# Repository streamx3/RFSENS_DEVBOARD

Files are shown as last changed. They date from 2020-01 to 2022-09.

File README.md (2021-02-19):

# RFSENS DEVBOARD

STM32 based devboard for IMU sensors with RTK GPS and LoRa modems

[Quick Schematic, BOM, DRC and Assembly in PDF](RFSENS-Altium/RFSENS.pdf)

## Actual device:

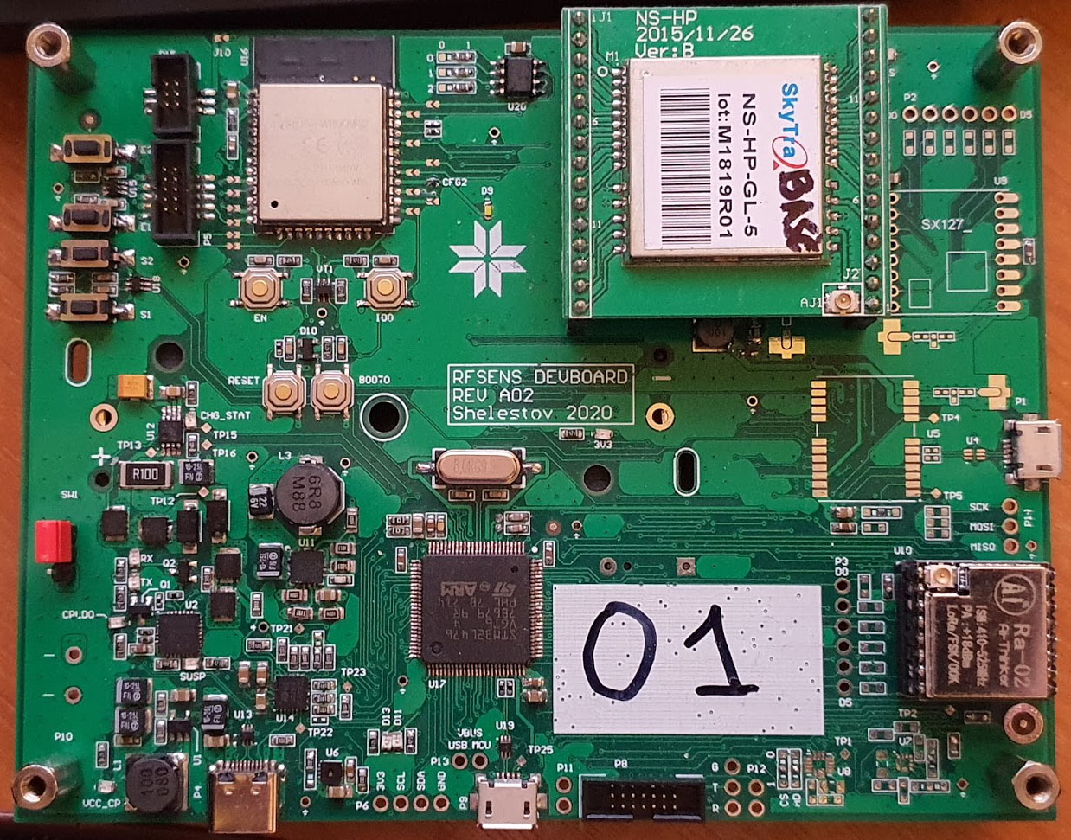
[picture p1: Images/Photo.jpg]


## Render:

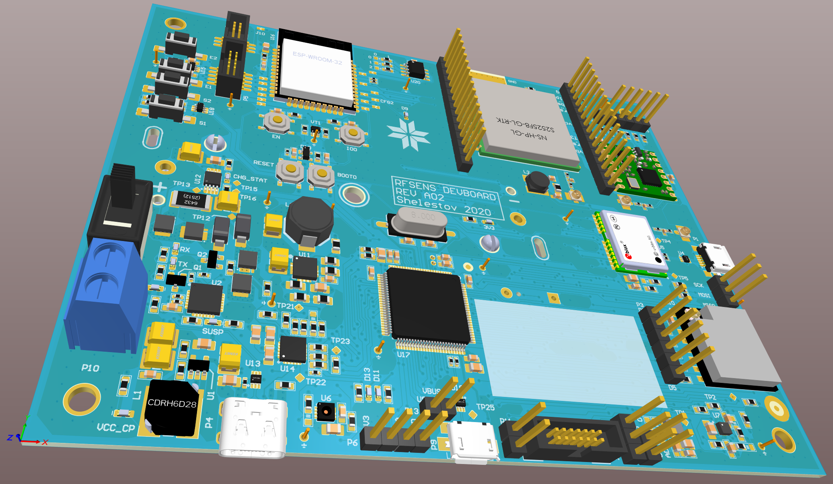
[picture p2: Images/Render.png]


## TOP:

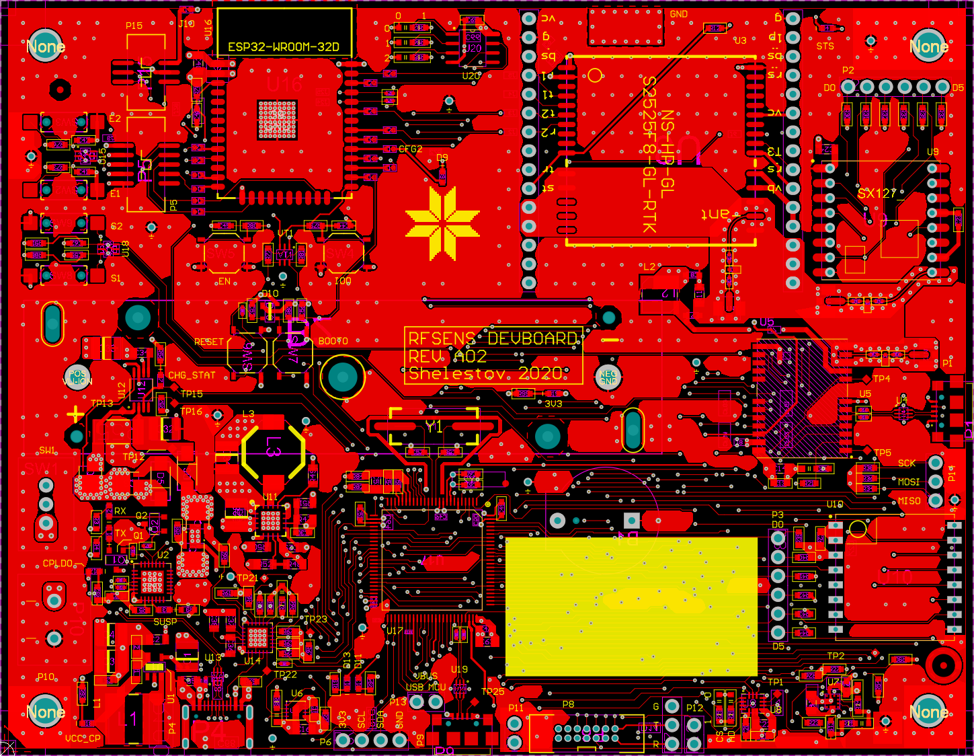
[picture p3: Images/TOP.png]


## BOT:

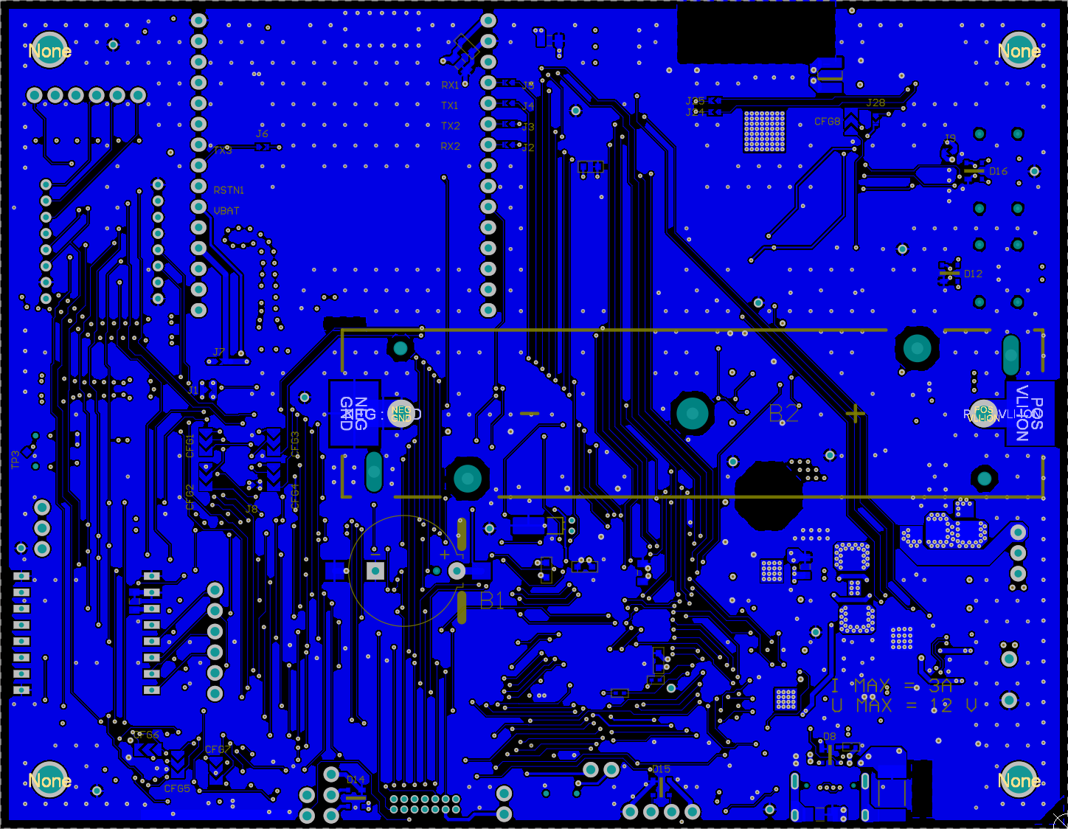
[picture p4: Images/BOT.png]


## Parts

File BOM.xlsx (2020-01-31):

DesignItemId | Description | Designator | Blueprint Quantity | Owned | Kosmodrom | PriceKosmodromUAH | RCS | PriceRCSUAH | OtherUA | PriceUAH | DigiKey | PriceDigiKey | Mouser | PriceMouser | Aliexpress | PriceAliexpress | HDR |  | PRICE USING | FULL Quantity | FULL Price | Light Quantity | Light Price
74HC2G14 | Dual inverting Schmitt trigger | U15, U18 | 2 |  | http://www.kosmodrom.com.ua/el.php?name=74HC2G14GW.125 | 4,5 |  |  |  |  |  |  |  |  |  |  |  |  | 4,5 | 2 | 9 | 2 | 9
18650_KEYS1042_HOLDER | 18650 Li-ion Battery Holder | B2 | 1 |  | http://www.kosmodrom.com.ua/el.php?name=KEYS1042 | 19,5 |  |  |  |  |  |  |  |  |  |  |  |  | 19,5 | 1 | 19.5 | 1 | 19.5
ANT-U.FL | Generic U.FL connector with 1 ANT + 3 GND | ANT1, ANT2, ANT3 | 3 | 6 | http://www.kosmodrom.com.ua/el.php?name=U.FL-R-SMT-1[10] | 4,75 | https://radiomag.prom.ua/p754064376-ipex-vilka-platu.html | 6 |  |  |  |  |  |  |  |  |  |  | 4,75 | 3 | 14.25 | 3 | 14.25
BC847BDW1T1G | Dual General Purpose Transistors NPN SOT 363 | VT1 | 1 |  | http://www.kosmodrom.com.ua/el.php?name=BC847BDW1T1G | 1,5 |  |  |  |  |  |  |  |  |  |  |  |  | 1,5 | 1 | 1.5 | 1 | 1.5
BH-6_UART_ESP-PROG | 1,27 mm 2x3 Header | P15 | 1 | 20 |  |  |  |  |  |  |  |  |  |  | https://www.aliexpress.com/item/4000400690967.html?spm=a2g0s.9042311.0.0.cbd34c4duRVTSV | 7 |  |  | 170.10 | 1 | 170.1 | 1 | 170.1
BH-10_JTAG_ESP-PROG | 1,27 mm 2x5 Header | P5 | 1 | 10 | http://www.kosmodrom.com.ua/el.php?name=BH1.27SMD-10 | 7 |  |  |  |  |  |  |  |  |  |  |  |  | 7 | 1 | 7 | 1 | 7
BH-14_JTAG_STLINK | 1,27 mm 2x7 Header | P8 | 1 | 10 | http://www.kosmodrom.com.ua/el.php?name=BH1.27-14 | 7,75 |  |  |  |  |  |  |  |  |  |  |  |  | 7,75 | 1 | 7.75 | 1 | 7.75
BSS84LT1G | Power MOSFET Single P-Channel SOT-23 -50 V, 10 _x0002_ | Q1, Q2 | 2 |  | http://www.kosmodrom.com.ua/el.php?name=BSS84LT1G | 1,75 |  |  |  |  |  |  |  |  |  |  |  |  | 1,75 | 2 | 3.5 | 2 | 3.5
C0402_10pF_50V | Ceramic capacitor | C11, C12, C25 | 3 |  |  |  | https://www.rcscomponents.kiev.ua/product/10pf-50v-1-cog-0402-vj0402a100fxacw1bc-vishay_162340.html | 0,3 |  |  |  |  |  |  |  |  |  |  | 0,3 | 3 | 0.9 | 3 | 0.9
C0603_1nF_25V | Ceramic capacitor | C41, C42, C43, C44, C45, C52, C56, C59, C62 | 9 |  | http://www.kosmodrom.com.ua/el.php?name=CP0603100050V10 | 0,75 |  |  |  |  |  |  |  |  |  |  |  |  | 0,75 | 9 | 6.75 | 9 | 6.75
C0603_4.3pF_50V | Ceramic capacitor | C60, C61 | 2 |  | http://www.kosmodrom.com.ua/el.php?name=CP06034.350V0.25 | 0,25 |  |  |  |  |  |  |  |  |  |  |  |  | 0,25 | 2 | 0.5 | 2 | 0.5
C0603_10nF_16V | Ceramic capacitor | C55 | 1 |  | http://www.kosmodrom.com.ua/el.php?name=CP06031050V10 | 0,25 |  |  |  |  |  |  |  |  |  |  |  |  | 0,25 | 1 | 0.25 | 1 | 0.25
C0603_10pF_25V | Ceramic capacitor | C30 | 1 |  |  |  | https://www.rcscomponents.kiev.ua/product/10pf-50v-np0-0-25pf-0603-4k-reel-c0603n100c500nt-hitano-kondensator-keramicheskij-smd_3301.html | 0,45 |  |  |  |  |  |  |  |  |  |  | 0,45 | 1 | 0.45 | 1 | 0.45
C0603_20pF_50V | Ceramic capacitor | C57, C58 | 2 |  | http://www.kosmodrom.com.ua/el.php?name=CP06032050V5 | 0,25 |  |  |  |  |  |  |  |  |  |  |  |  | 0,25 | 2 | 0.5 | 2 | 0.5
C0603_100nF_16V | Ceramic capacitor | C5, C6, C7, C8, C9, C13, C15, C17, C19, C20, C21, C23, C26, C46, C47, C48, C49, C50, C51, C54, C65 | 21 |  | http://www.kosmodrom.com.ua/el.php?name=CP06030.125V8020 | 1 |  |  |  |  |  |  |  |  |  |  |  |  | 1 | 21 | 21 | 21 | 21
C0805_1uF_25V | Ceramic capacitor | C2, C10, C14, C16, C18, C22, C24, C27, C29, C35, C36, C37, C38, C40, C53, C63, C64, C66 | 18 |  | http://www.kosmodrom.com.ua/el.php?name=CP0805125V10 | 1 |  |  |  |  |  |  |  |  |  |  |  |  | 1 | 18 | 18 | 18 | 18
C0805_100nF_25V | Ceramic capacitor | C34, C67 | 2 |  |  |  | https://www.rcscomponents.kiev.ua/product/100nf-25v-x7r-10-0805-4k-reel-c0805b104k250nt-hitano-kondensator-keramicheskij-smd_2259.html | 1,1 |  |  |  |  |  |  |  |  |  |  | 1,1 | 2 | 2.2 | 2 | 2.2
C1206_1nF_2KV | Ceramic capacitor | C68 | 1 |  |  |  | https://www.rcscomponents.kiev.ua/product/1nf-2000v-x7r-10-1206-3k-reel-1206b102k202n3-hitano-kondensatory-keramicheskie-smd_11455.html | 1,7 |  |  |  |  |  |  |  |  |  |  | 1,7 | 1 | 1.7 | 1 | 1.7
CAP_B_10uF_6V3 | Tantalum capacitor | C33 | 1 |  |  |  | https://www.rcscomponents.kiev.ua/product/10uf-10v-size-b-10-tajb106k010r-avx-kondensator-tantalovyj-smd_14318.html | 4 |  |  |  |  |  |  |  |  |  |  | 4 | 1 | 4 | 1 | 4
CAP_B_10uF_25V | Tantalum capacitor | C1, C3, C4, C28, C32 | 5 |  | http://www.kosmodrom.com.ua/el.php?name=TR3B106K025C0450 | 6,75 | https://www.rcscomponents.kiev.ua/product/10uf-25v-size-b-10-tajb106k025rnj-avx-kondensator-tantalovyj-smd_39635.html | 5,5 |  |  |  |  |  |  |  |  |  |  | 5,5 | 5 | 27.5 | 5 | 27.5
CAP_B_22uF_6V3 | Tantalum capacitor | C31 | 1 |  |  |  | https://www.rcscomponents.kiev.ua/product/22uf-6-3v-size-b-20-tcscs0j226mbar-samsung-kondensator-tantalovyj-smd_6588.html | 4,5 |  |  |  |  |  |  |  |  |  |  | 4,5 | 1 | 4.5 | 1 | 4.5
CAP_B_100uF_6V3 | Tantalum capacitor | C39 | 1 |  |  |  | https://www.rcscomponents.kiev.ua/product/100uf-6-3v-size-b-10-tajb107k006rnj-avx-kondensator-tantalovyj-smd_39633.html | 5,5 |  |  |  |  |  |  |  |  |  |  | 5,5 | 1 | 5.5 | 1 | 5.5
CON-USB-Micro/Mini | Mini/Micro USB B Type RCPT | P1, P9 | 2 |  | http://www.kosmodrom.com.ua/el.php?name=ESB228110100Z | 2,5 |  |  |  |  |  |  |  |  |  |  |  |  | 2,5 | 2 | 5 | 2 | 5
CON-USB-TYPE-C-B-229 | Type C 3A Throughthole Shell, USB2 + PD SMD pins | P4 | 1 |  | http://www.kosmodrom.com.ua/el.php?name=USB-Type-C-B-229 | 8,25 |  |  |  |  |  |  |  |  |  |  |  |  | 8,25 | 1 | 8.25 | 1 | 8.25
CP2102-GM | SINGLE-CHIP USB-TO-UART BRIDGE | U2 | 1 |  | http://www.kosmodrom.com.ua/el.php?name=CP2102-GMR | 46,75 |  |  |  |  |  |  |  |  |  |  |  |  | 46,75 | 1 | 46.75 | 1 | 46.75
CR12XX_BH500 | Coin Cell Battery 3V 12 X 2.5 mm 48mA Holder | B1 | 1 |  | http://www.kosmodrom.com.ua/el.php?name=BH500 | 8,25 |  |  |  |  |  |  |  |  |  |  |  |  | 8,25 | 1 | 8.25 | 1 | 8.25
D_SS-34 | Rectifier, Schottky; DO-214AB; 3.0A IF; 0.75V; 40V; 100A IFRM; 10000V/us; 1000pF | D5, D6 | 2 |  |  |  | https://www.rcscomponents.kiev.ua/product/ss34a_123319.html | 4 |  |  |  |  |  |  |  |  |  |  | 4 | 2 | 8 | 2 | 8
DC_TERM_BLK |  | P10 | 1 |  |  |  | https://www.rcscomponents.kiev.ua/product/klemmnik-dg301-5-0-02p-12-00a-h-2kont-sinij-shlicz-degson_19759.html | 1,75 |  |  |  |  |  |  |  |  |  |  | 1,75 | 1 | 1.75 | 1 | 1.75
ESP32-WROOM-32D | IC: SoC; GPIO, I2C, I2S, IR, SD, SDIO, SPI, UART; 2.7Г·3.6VDC; 20dBm | U16 | 1 | 2 |  |  |  |  | https://www.olx.ua/uk/obyavlenie/esp-wroom-32-esp-32-module-IDGzoQv.html | 135 |  |  |  |  | https://www.aliexpress.com/item/32963147246.html | 2,5 |  |  | 60.75 | 1 | 60.75 | 1 | 60.75
HEADER 1x2 |  | P11, P12, P13 | 3 |  |  |  |  |  |  |  |  |  |  |  |  |  | 2 | 6 | 0.00 | 3 | 0 | 3 | 0
HEADER 1x3 |  | P14 | 1 |  |  |  |  |  |  |  |  |  |  |  |  |  | 3 | 3 | 0.00 | 1 | 0 | 1 | 0
HEADER 1x4 |  | P6 | 1 |  |  |  |  |  |  |  |  |  |  |  |  |  | 4 | 4 | 0.00 | 1 | 0 | 1 | 0
HEADER 1x6 |  | P2, P3 | 2 |  |  |  |  |  |  |  |  |  |  |  |  |  | 5 | 10 | 0.00 | 2 | 0 | 2 | 0
IRFHM9331 | -30V Single P-Channel HEXFET Power MOSFET in a PQFN 3mm x 3mm package | Q3, Q4, Q5, Q6 | 4 |  | http://www.kosmodrom.com.ua/el.php?name=IRFHM9331TRPBF | 11,75 |  |  |  |  |  |  |  |  |  |  |  |  | 11,75 | 4 | 47 | 4 | 47
L_CDHR8D43_6.8uH_3.9A | Inductor Generic | L3 | 1 |  | http://www.kosmodrom.com.ua/el.php?name=CDRH8D43NP-6R8NC | 12 |  |  |  |  |  |  |  |  |  |  |  |  | 12 | 1 | 12 | 1 | 12
L_CDRH4D18_10uH_0.61A | Inductor Generic | L2 | 1 |  | http://www.kosmodrom.com.ua/el.php?name=CDRH4D18NP-100NC | 7 |  |  |  |  |  |  |  |  |  |  |  |  | 7 | 1 | 7 | 1 | 7
L_CDRH6D28_10uH_1.7A | Inductor Generic | L1 | 1 |  | http://www.kosmodrom.com.ua/el.php?name=CDRH6D28NP-100NC | 6,25 |  |  |  |  |  |  |  |  |  |  |  |  | 6,25 | 1 | 6.25 | 1 | 6.25
LED | Led General | D1, D2, D3, D4, D7, D9, D11, D13, D17, D18, D19 | 11 | 3000 |  |  |  |  |  |  |  |  |  |  |  |  |  |  | 0.00 | 11 | 0 | 11 | 0
LIS3MDLTR | LIS3MDL Series 3 Axis В±2/В±8/В±12/В±16 g 3.6V High Performance Magnetometer LGA-12 | U7 | 1 |  | http://www.kosmodrom.com.ua/el.php?name=LIS3MDLTR | 57,5 |  |  |  |  |  |  |  |  |  |  |  |  | 57,5 | 1 | 57.5 | 1 | 57.5
LSM6DSOX | Gygo and acceletometer programmable I2C master IC | U8 | 1 | 10 |  |  |  |  |  |  | https://www.digikey.com/product-detail/en/stmicroelectronics/LSM6DSOXTR/497-18367-1-ND/9841887 | 5,25 | https://www.mouser.com/ProductDetail/STMicroelectronics/LSM6DSOXTR | 4,76 |  |  |  |  | 115.67 | 1 | 115.668 | 1 | 115.668
M24C64-WDW6T | 64Kbit Serial I2C Bus EEPROM | U20 | 1 |  | http://www.kosmodrom.com.ua/el.php?name=M24C64-WMN6TP | 5 |  |  |  | - |  |  |  |  |  |  |  |  | 5 | 1 | 5 | 1 | 5
MCP73843 | MCP73843 Single Li-ion cell charger IC | U12 | 1 |  | http://www.kosmodrom.com.ua/el.php?name=MCP73843-420IMS | 64,25 |  |  |  |  |  |  |  |  |  |  |  |  | 64,25 | 1 | 64.25 | 1 | 64.25
NEO | u-blox NEO GNSS module | U5 | 1 |  |  |  |  |  | https://www.u-blox.com/en/product/neo-m8-series | 22.10 |  |  |  |  |  |  |  |  | 597.36 | 1 | 597.363 | 1 | 597.363
NS-HP-GL | NS-HP-GL / S2525F8-GL-RTK in SMD | U3 | 1 | 2 |  |  |  |  | http://navspark.mybigcommerce.com/ns-hp-gl-gps-glonass-rtk-receiver/ | 70 |  |  |  |  |  |  |  |  | 1892.10 | 1 | 1892.1 |  | 0
PRTR5V0U2X,215 | PRTR5V0U2X - Ultra low capacitance double rail-to-rail ESD protection diode | D8, D10, D12, D14, D15, D16 | 6 | 10 | http://www.kosmodrom.com.ua/el.php?name=PRTR5V0U2X.215 | 3,25 |  |  |  |  |  |  |  |  |  |  |  |  | 3,25 | 6 | 19.5 | 6 | 19.5
Q_8MHz | Quartz resonator 8MHz | Y1 | 1 |  | http://www.kosmodrom.com.ua/el.php?name=KX-K-8.0-MHz | 6 |  |  |  |  |  |  |  |  |  |  |  |  | 6 | 1 | 6 | 1 | 6
Q_32.768KHz | Quartz resonator 32.768KHz | Y2 | 1 |  | http://www.kosmodrom.com.ua/el.php?name=KX-38T-32.768-kHz-6pF | 5 |  |  |  |  |  |  |  |  |  |  |  |  | 5 | 1 | 5 | 1 | 5
R0402_0R | Resistor General | R13, R14, R15, R16, R17, R18, R45, R46, R53, R58, R74, R75, R98 | 13 |  | http://www.kosmodrom.com.ua/el.php?name=0402SMDRES0OM5 | 0,04 | https://www.rcscomponents.kiev.ua/product/0-ohm-0402-wr04x000ptl-walsin_105536.html | 0,05 |  |  |  |  |  |  |  |  |  |  | 0,04 | 13 | 0.52 | 13 | 0.52
R0402_51R | Resistor General | R6, R7, R8, R10, R83, R86, R87, R101, R102 | 9 |  | http://www.kosmodrom.com.ua/el.php?name=0402SMDRES51OM5 | 0,03 | https://www.rcscomponents.kiev.ua/product/51-ohm-5-1-16w-50v-0402-rc0402jr-51r-hitano_11504.html | 0,05 |  |  |  |  |  |  |  |  |  |  | 0,03 | 9 | 0.27 | 9 | 0.27
R0603_0R | Resistor General | R21, R23, R82, R84 | 4 |  |  |  | https://www.rcscomponents.kiev.ua/product/0-ohm-5-0-1w-50v-0603-rc0603jr-0r-hitano-rezistor-smd_4159.html | 0,06 |  |  |  |  |  |  |  |  |  |  | 0,06 | 4 | 0.24 | 4 | 0.24
R0603_1K | Resistor General | R69, R70 | 2 |  |  |  | https://www.rcscomponents.kiev.ua/product/1-kohm-5-0-1w-50v-0603-0603waj0102t5e-uniohm_147392.html | 0,06 |  |  |  |  |  |  |  |  |  |  | 0,06 | 2 | 0.12 | 2 | 0.12
R0603_1K_1% | Resistor General | R60 | 1 |  |  |  | https://www.rcscomponents.kiev.ua/product/1-kohm-1-0-1w-50v-0603-rc0603fr-1kr-hitano-rezistor-smd_95976.html | 0,07 |  |  |  |  |  |  |  |  |  |  | 0,07 | 1 | 0.07 | 1 | 0.07
R0603_4K7 | Resistor General | R5, R26, R27, R54, R90 | 5 | 3000 |  |  |  |  |  |  |  |  |  |  |  |  |  |  | 0.00 | 5 | 0 | 5 | 0
R0603_10K | Resistor General | R22, R30, R31, R32, R33, R34, R35, R36, R37, R38, R39, R40, R41, R42, R43, R44, R61, R62, R63, R64, R65, R66, R67, R68, R73, R76, R88, R91 | 28 | 3000 |  |  | https://www.rcscomponents.kiev.ua/product/10-kohm-5-0-1w-50v-0603-rc0603jr-0710kl-yageo_107096.html | 0,06 |  |  |  |  |  |  |  |  |  |  | 0.00 | 28 | 0 | 28 | 0
R0603_10K_1% | Resistor General | R59 | 1 |  |  |  | https://www.rcscomponents.kiev.ua/product/10-kohm-1-0-1w-50v-0603-rc0603fr-10kr-hitano-rezistor-smd_8516.html | 0,07 |  |  |  |  |  |  |  |  |  |  | 0.00 | 1 | 0 | 1 | 0
R0603_12K | Resistor General | R77, R78, R81 | 3 | 3000 |  |  | https://www.rcscomponents.kiev.ua/product/12-kohm-5-0-1w-50v-0603-rc0603jr-12k0-hitano-rezistor-smd_1014.html | 0,06 |  |  |  |  |  |  |  |  |  |  | 0.00 | 3 | 0 | 3 | 0
R0603_20K_1% | Resistor General | R2 | 1 |  |  |  | https://www.rcscomponents.kiev.ua/product/20-kohm-1-0-1w-50v-0603-rc0603fr-20kr-hitano-rezistor-smd_16748.html | 0,07 |  |  |  |  |  |  |  |  |  |  | 0.00 | 1 | 0 | 1 | 0
R0603_100K | Resistor General | R57 | 1 | 3000 |  |  |  |  |  |  |  |  |  |  |  |  |  |  | 0.00 | 1 | 0 | 1 | 0
R0603_105K_1% | Resistor General | R1 | 1 |  |  |  | https://www.rcscomponents.kiev.ua/product/105-kohm-1-0-1w-50v-0603-rc0603fr-105k0-hitano-rezistor-smd_39565.html | 0,07 |  |  |  |  |  |  |  |  |  |  | 0.00 | 1 | 0 | 1 | 0
R0603_470R | Resistor General | R3, R4, R9, R12, R19, R56, R72, R79, R80, R85, R92, R93, R94, R99 | 14 | 3000 |  |  |  |  |  |  |  |  |  |  |  |  |  |  | 0.00 | 14 | 0 | 14 | 0
R0805_0R | Resistor General | R11 | 1 | 3000 |  |  |  |  |  |  |  |  |  |  |  |  |  |  | 0.00 | 1 | 0 | 1 | 0
R0805_1M_1% | Resistor General | R48, R49, R50 | 3 |  | http://www.kosmodrom.com.ua/el.php?name=SMDRES08051MOM1 | 0,17 | https://www.rcscomponents.kiev.ua/product/1-mohm-1-0-125w-150v-0805-rc0805fr-1mr-hitano_11448.html | 0,11 |  |  |  |  |  |  |  |  |  |  | 0,11 | 3 | 0.33 | 3 | 0.33
R0805_261K_1% | Resistor General | R52 | 1 |  |  |  | https://www.rcscomponents.kiev.ua/product/261-kohm-1-0-125w-150v-0805-rc0805fr-261k-hitano-rezistor-smd_27749.html | 0,11 |  |  |  |  |  |  |  |  |  |  | 0,11 | 1 | 0.11 | 1 | 0.11
R0805_300K_1% | Resistor General | R51 | 1 |  | http://www.kosmodrom.com.ua/el.php?name=SMDRES0805300KOM1 | 0,12 | https://www.rcscomponents.kiev.ua/product/300-kohm-1-0-125w-150v-0805-rezistor-smd_3009.html | N/A |  |  |  |  |  |  |  |  |  |  | 0,12 | 1 | 0.12 | 1 | 0.12
R0805_560K_1% | Resistor General | R47 | 1 |  | http://www.kosmodrom.com.ua/el.php?name=SMDRES0805560KOM1 | 0,17 | https://www.rcscomponents.kiev.ua/product/560-kohm-1-0-125w-150v-0805-rc0805fr-560kr-hitano_1487.html | 0,11 |  |  |  |  |  |  |  |  |  |  | 0,11 | 1 | 0.11 | 1 | 0.11
R2512_0R1_1% | Resistor General | R55 | 1 |  | http://www.kosmodrom.com.ua/el.php?name=SMDRES25120.1OM5 | 2,25 |  |  |  |  |  |  |  |  |  |  |  |  | 2,25 | 1 | 2.25 | 1 | 2.25
R2512_1M_5% | Resistor General | R100 | 1 |  |  |  | https://www.rcscomponents.kiev.ua/product/1-mohm-5-1w-2512-rc2512jk-1mr-hitano-rezistor-smd_51251.html | 0,75 |  |  |  |  |  |  |  |  |  |  | 0,75 | 1 | 0.75 | 1 | 0.75
RA-02 | RA-02 LoRa modem by Ai-Thinker | U10 | 1 | 6 |  |  |  |  | https://1wire.com.ua/ra-02-lora-sx1278-433mhz.html | 127,66 |  |  |  |  | https://www.aliexpress.com/item/32976593804.html | 2,65 |  |  | 64.39 | 1 | 64.395 | 1 | 64.395
RJ0603_10K | Resistor General | R20, R24, R25, R28, R29, R71, R89, R95, R96, R97 | 10 | 3000 |  |  | https://www.rcscomponents.kiev.ua/product/10-kohm-5-0-1w-50v-0603-rc0603jr-0710kl-yageo_107096.html | 0,06 |  |  |  |  |  |  |  |  |  |  | 0,06 | 10 | 0.6 | 10 | 0.6
SHT30-DIS | Temp & Humidity sensor | U6 | 1 |  | http://www.kosmodrom.com.ua/el.php?name=SHT30-DIS-B | 75,75 |  |  |  |  |  |  |  |  |  |  |  |  | 75,75 | 1 | 75.75 | 0 | 0
STM32L476VGT | Ultra-low-power Cortex-M4 32-bit MCU+FPU, 100DMIPS, up to 1MB Flash, 128 KB SRAM, USB OTG FS, LCD | U17 | 1 | 6 |  |  |  |  | https://step-elektronika.prom.ua/p499466797-mikrokontroller-shirokogo-naznacheniya.html | 253,84 | https://www.digikey.com/product-detail/en/stmicroelectronics/STM32L476VGT6/497-15873-ND/5344349 | 10.55 | https://www.mouser.com/ProductDetail/STMicroelectronics/STM32L476VGT6TR | 10.55 |  |  |  |  | 253,84 | 1 | 253.84 | 1 | 253.84
STUSB1602 | USB Type-C controller with TX/RX line driver and BMC | U14 | 1 |  |  |  | https://www.rcscomponents.kiev.ua/product/stusb1602aqtr_132330.html | 45 |  |  |  |  |  |  |  |  |  |  | 45 | 1 | 45 | 1 | 45
SWI_2.54_2POS | Generich 2 pos switch | SW1 | 1 |  |  |  |  |  |  |  |  |  |  |  |  |  | 3 | 3 | 0.00 | 1 | 0 | 1 | 0
SWITCH_GEN_2P | SWITCH DIP 4.3 mm | SW2, SW3, SW8, SW9 | 4 |  | http://www.kosmodrom.com.ua/el.php?name=TACT-35N-F | 1,25 |  |  |  |  |  |  |  |  |  |  |  |  | 1,25 | 4 | 5 | 4 | 5
SWITCH_GEN_4P | SWITCH DIP 4.3 mm | SW4, SW5, SW6, SW7 | 4 |  | http://www.kosmodrom.com.ua/el.php?name=TACT-5X5X1.5 | 0,5 |  |  |  |  |  |  |  |  |  |  |  |  | 0,5 | 4 | 2 | 4 | 2
SX1278 | SX1278 LoRa modem | U9 | 1 | 2 |  |  |  |  |  |  |  |  |  |  | https://www.aliexpress.com/item/32802402060.html | 3,76 |  |  | 91.37 | 1 | 91.368 |  | 0
TPS62110RSAT | TPS6211x 17-V, 1.5-A, Synchronous Step-Down Converter | U11 | 1 |  | http://www.kosmodrom.com.ua/el.php?name=TPS62110RSAT | 64 |  |  |  |  |  |  |  |  |  |  |  |  | 64 | 1 | 64 | 1 | 64
TPS560200DBVR | TPS560200 4.5-V to 17-V Input, 500-mA Synchronous Step-Down Converter With Advanced Eco-Mode™ | U1 | 1 |  | http://www.kosmodrom.com.ua/el.php?name=TPS560200DBVR | 6,75 |  |  |  |  |  |  |  |  |  |  |  |  | 6,75 | 1 | 6.75 | 1 | 6.75
UART_2.54 |  | P7 | 1 |  |  |  |  |  |  |  |  |  |  |  |  |  | 3 | 3 | 0.00 | 1 | 0 | 1 | 0
USBLC6-2 | Very low capacitance ESD protection | U4, U13, U19 | 3 |  | http://www.kosmodrom.com.ua/el.php?name=USBLC6-2P6 | 4,25 |  |  |  |  |  |  |  |  |  |  |  |  | 4,25 | 3 | 12.75 | 3 | 12.75
PLS-40 |  |  |  |  | http://www.kosmodrom.com.ua/el.php?name=PLS-40-BLACK | 1 |  |  |  |  |  |  |  |  |  |  |  | 29 | 0.80 UAH | 0.8 | 0.64 | 0.8 | 0.64
 |  |  |  |  |  |  |  |  |  |  |  | 1 USD to UAH | 24.3 |  |  | To build | Full Boards | 2 |  | Total per 1 UAH | 3926.714 |  | 1867.496
 |  |  |  |  |  |  |  |  |  |  |  | 1 EUR to UAH | 27.03 |  |  |  | Light boards | 2 |  | Total per 1 USD | 157.06856 |  | 74.69984
 |  |  |  |  |  |  |  |  |  |  |  |  |  |  |  |  |  |  |  | Total UAH | 11588.42
 |  |  |  |  |  |  |  |  |  |  |  |  |  |  |  |  |  |  |  | Total USD | 476.8897119

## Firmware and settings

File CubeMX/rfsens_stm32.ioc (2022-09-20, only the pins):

Mcu.UserName=STM32L476VGTx
PA0.Signal=UART4_TX
PA1.Signal=UART4_RX
PA10.Signal=USART1_RX
PA11.Signal=USB_OTG_FS_DM
PA12.Signal=USB_OTG_FS_DP
PA2.Signal=USART2_TX
PA3.Signal=USART2_RX
PA5.Signal=SPI1_SCK
PA6.Signal=SPI1_MISO
PA7.Signal=SPI1_MOSI
PB10.Signal=LPUART1_RX
PB11.Signal=LPUART1_TX
PB13.Signal=I2C2_SCL
PB14.Signal=I2C2_SDA
PB6.Signal=USART1_TX
PB7.Signal=I2C1_SDA
PB8.Signal=I2C1_SCL
PC12.Signal=UART5_TX
PC2.Signal=SPI2_MISO
PC3.Signal=SPI2_MOSI
PC4.Signal=USART3_TX
PC5.Signal=USART3_RX
PC7.GPIO_Label=STLED1
PC7.Signal=GPIO_Output
PD1.Signal=SPI2_SCK
PD2.Signal=UART5_RX
PE1.GPIO_Label=LSM_INT
PE1.Signal=GPXTI1
PE2.GPIO_Label=RF1_D0
PE2.Signal=GPXTI2
PE3.GPIO_Label=RF1_D1
PE3.Signal=GPXTI3
PE4.GPIO_Label=RF1_D2
PE4.Signal=GPXTI4
PE5.GPIO_Label=RF2_D0
PE5.Signal=GPXTI5

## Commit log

2019-10-13 Minor fixes
    [04-SENSORS.SchDoc]
2019-10-24 Minor changes
    [01-UART.SchDoc, 02-MCU.SchDoc, 03-GPS.SchDoc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]
2019-11-02 Minor changes to Type C and Controller schematics
    [07-POWER.SchDoc, 08-TYPE-C-PORT.SchDoc]
2019-11-12 Changes from the review
    [01-UART.SchDoc, 03-GPS.SchDoc]
2019-11-22 Final Schematic
    [00-OVERVIEW.SchDoc, 000-PDN.SchDoc, 02-ESP32.SchDoc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]
2019-11-22 Error fixes
    [00-OVERVIEW.SchDoc, 000-PDN.SchDoc, 01-UART.SchDoc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]
2019-11-22 Review results
    [01-UART.SchDoc]
2019-12-15 + Added jumpers instead of solderjoints + Fioxed internal layer nets
    [01-UART.SchDoc, 05-STM32.SchDoc, 07-POWER.SchDoc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]
2019-12-16 + Added capacitor and resistor to Type-C Shield for ESD + Removed polugon from behind coils + Cleaned eveything from behind anthena + Signed LEDs + Made wider track for LEDs + Removed coper from mech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
    [08-TYPE-C-PORT.SchDoc]
2019-12-17 DRC fix
    [00-OVERVIEW.SchDoc, 03-GPS.SchDoc, 05-STM32.SchDoc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]
2019-12-27 Added LORA SPI header
    [06-LORA.SchDoc, esp32-gps-collar.PrjPcb]
2019-12-27 Added via stitching
    [03-GPS.SchDoc]
2019-12-31 Last minor fixes and creation of Gerbers
    [SAC100001-PB-Collar.GBL, SAC100001-PB-Collar.GBO, SAC100001-PB-Collar.GBS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]
2020-01-10 Fixed connectors to Match ESP-prog
    [02-ESP32.SchDoc, 05-STM32.SchDoc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]
2020-01-21 BOM quickfix
    [07-POWER.SchDoc, esp32-gps-collar.PrjPcb]
2020-01-23 Added final BOM
    [00-OVERVIEW.SchDoc, 01-UART.SchDoc, 02-ESP32.SchDoc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]
2020-01-23 Made Excel from BOM
    [esp32-gps-collar.xlsx]
2020-01-31 Documentation update
    [esp32-gps-collar.PrjPcb, esp32-gps-collar.xlsx]
2021-02-19 Updated project structure and regenerated the PDF from new OutJob.
    [00-OVERVIEW.SchDoc, 000-PDN.SchDoc, 01-UART.SchDoc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]
2021-02-19 Added images and made minor fixes for USBLC6-2
    [03-GPS.SchDoc, 05-STM32.SchDoc, 08-TYPE-C-PORT.SchDoc]
2021-02-19 Updated manufacturing files
    [RFSENS.PrjPcb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]
